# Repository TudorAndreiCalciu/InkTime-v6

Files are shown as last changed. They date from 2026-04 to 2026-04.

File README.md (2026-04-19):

# InkTime v6 - Smartwatch cu Display E-Paper (nRF52840)

InkTime v6 este un proiect hardware de tip wearable, conceput pentru eficiență energetică extremă și afișaj permanent. Dispozitivul utilizează un ecran E-Paper de 1.54 inch și este bazat pe microcontrolerul nRF52840, oferind conectivitate Bluetooth Low Energy (BLE) într-un format compact.

---

## 1. Diagrama Bloc a Sistemului

Această diagramă ilustrează arhitectura hardware și fluxul de alimentare și date între module:

```mermaid
graph TD
    subgraph "Power Management"
        BATT((Baterie LiPo 3.7V)) --> CHG[Charger TP4056]
        CHG --> LDO[Regulator LDO 3.3V AP2112K]
    end

    subgraph "Processing Core"
        MCU[Holyiot nRF52840<br/>ARM Cortex-M4F]
    end

    subgraph "Peripherals"
        EPD[Display E-Paper 1.54'']
        SENS[Senzori I2C + Pull-ups]
        BTNS[3x User Buttons]
        DEBUG[Interfață Debug SWD]
    end

    %% Conexiuni Alimentare
    LDO -->|3.3V VCC| MCU
    LDO -->|3.3V VCC| EPD
    LDO -->|3.3V VCC| SENS

    %% Conexiuni Date
    MCU <-->|SPI Bus| EPD
    MCU <-->|I2C SDA/SCL| SENS
    BTNS ---|GPIO / Interrupt| MCU
    DEBUG <-->|SWDIO / SWCLK| MCU
```

---

## 2. Descrierea Hardware și Funcționalitate

Dispozitivul a fost proiectat respectând principiile de consum ultra-scăzut (Ultra-Low Power):

* **Microcontroler (MCU):** Modulul **Holyiot nRF52840**. Ales pentru consumul minim în modul Deep Sleep (~3µA) și pentru suportul nativ de conectivitate BLE și USB. Acesta gestionează întreaga logică a ceasului.
* **Display E-Paper:** Un ecran de 1.54 inch conectat prin magistrala **SPI**. Tehnologia bistabilă permite afișarea permanentă a informațiilor fără consum de energie (0mA în stare statică).
* **Interfața I2C:** Configurație cu rezistențe de pull-up de 4.7kΩ pentru a asigura stabilitatea semnalului către senzori (accelerometru/RTC).
* **Management Alimentare:** Încărcarea bateriei LiPo se face prin portul USB utilizând controller-ul **TP4056**. Tensiunea este stabilizată la 3.3V prin regulatorul LDO **AP2112K-3.3**.

---

## 3. Maparea Pinilor (Pinout nRF52840)

Alocarea pinilor a fost realizată strategic pentru a facilita rutarea semnalelor pe PCB:

| Pin nRF52 | Conectat la | Interfață | Rol / Justificare |
| :--- | :--- | :--- | :--- |
| **P1.00** | `EPD_MOSI` | SPI | Date transmise către display. |
| **P0.22** | `EPD_SCK` | SPI | Semnalul de tact (Clock) pentru SPI. |
| **P0.20** | `EPD_CS` | SPI (CS) | Chip Select - Activează display-ul. |
| **P0.17** | `EPD_DC` | GPIO | Data/Command - Comută între date și comenzi. |
| **P0.15** | `EPD_RES` | GPIO | Reset Hardware - Inițializează driverul EPD. |
| **P0.13** | `EPD_BUSY` | GPIO (In) | Busy Signal - Detectează finalul refresh-ului. |
| **P0.26** | `I2C_SDA` | I2C | Date pentru magistrala I2C. |
| **P0.24** | `I2C_SCL` | I2C | Clock pentru magistrala I2C. |
| **P0.02** | `BTN1` | GPIO (IRQ) | Buton 1 - Configurat pentru Wake-up. |
| **P0.29** | `BTN2` | GPIO | Buton 2 - Input utilizator (Sus/Select). |
| **P0.31** | `BTN3` | GPIO | Buton 3 - Input utilizator (Jos/Back). |
| **P0.11** | `SWCLK` | Debug | Clock pentru programare (Hardware dedicated). |
| **P0.12** | `SWDIO` | Debug | Date pentru programare (Hardware dedicated). |

---

## 4. Bill of Materials (BOM)

Componentele utilizate pe placă cu link-uri către JLCPCB și documentație:

| Componentă | Pachet | Rol | Link JLCPCB | Datasheet |
| :--- | :--- | :--- | :--- | :--- |
| **nRF52840 Holyiot** | SMD Module | MCU + BLE | [C517331](https://jlcpcb.com/partdetail/C517331) | [Link PDF](https://www.mouser.com/datasheet/3/926/1/nrf52840_soc_v3.0.pdf) |
| **AP2112K-3.3** | SOT-23-5 | LDO 3.3V | [C51118](https://jlcpcb.com/partdetail/C51118) | [Link PDF](https://www.diodes.com/assets/Datasheets/AP2112.pdf) |
| **TP4056** | SOP-8 | Charger | [C16581](https://jlcpcb.com/partdetail/C16581) | [Link PDF](https://dlnmh9ip6v2uc.cloudfront.net/datasheets/Prototyping/TP4056.pdf) |
| **Butoane Tactile** | 3x4mm SMD | Input | [C318884](https://jlcpcb.com/partdetail/C318884) | [Link PDF](https://datasheet.lcsc.com/lcsc/1811061726_XKB-Connection-TS-1187A-B-A-B_C318884.pdf) |
| **Conector FPC 24P** | 0.5mm Pitch | EPD Port | [C46954](https://jlcpcb.com/partdetail/C46954) | [Link PDF](https://datasheet.lcsc.com/lcsc/1810010313_XKB-Enterprise-F31L-1A7H1-24050-T241_C46954.pdf) |

---

## 5. Analiza Consumului Energetic

Sistemul este proiectat să funcționeze cu o baterie LiPo de **250 mAh**.

* **Consum Deep Sleep:** ~5 µA (MCU + LDO quiescent current).
* **Consum Refresh E-Paper:** ~8 mA (timp de 2 secunde).
* **Consum Mediu:** ~0.27 mA (calculat pentru un refresh pe minut).
* **Autonomie Estimată:** Aproximativ **38 de zile** de funcționare continuă.

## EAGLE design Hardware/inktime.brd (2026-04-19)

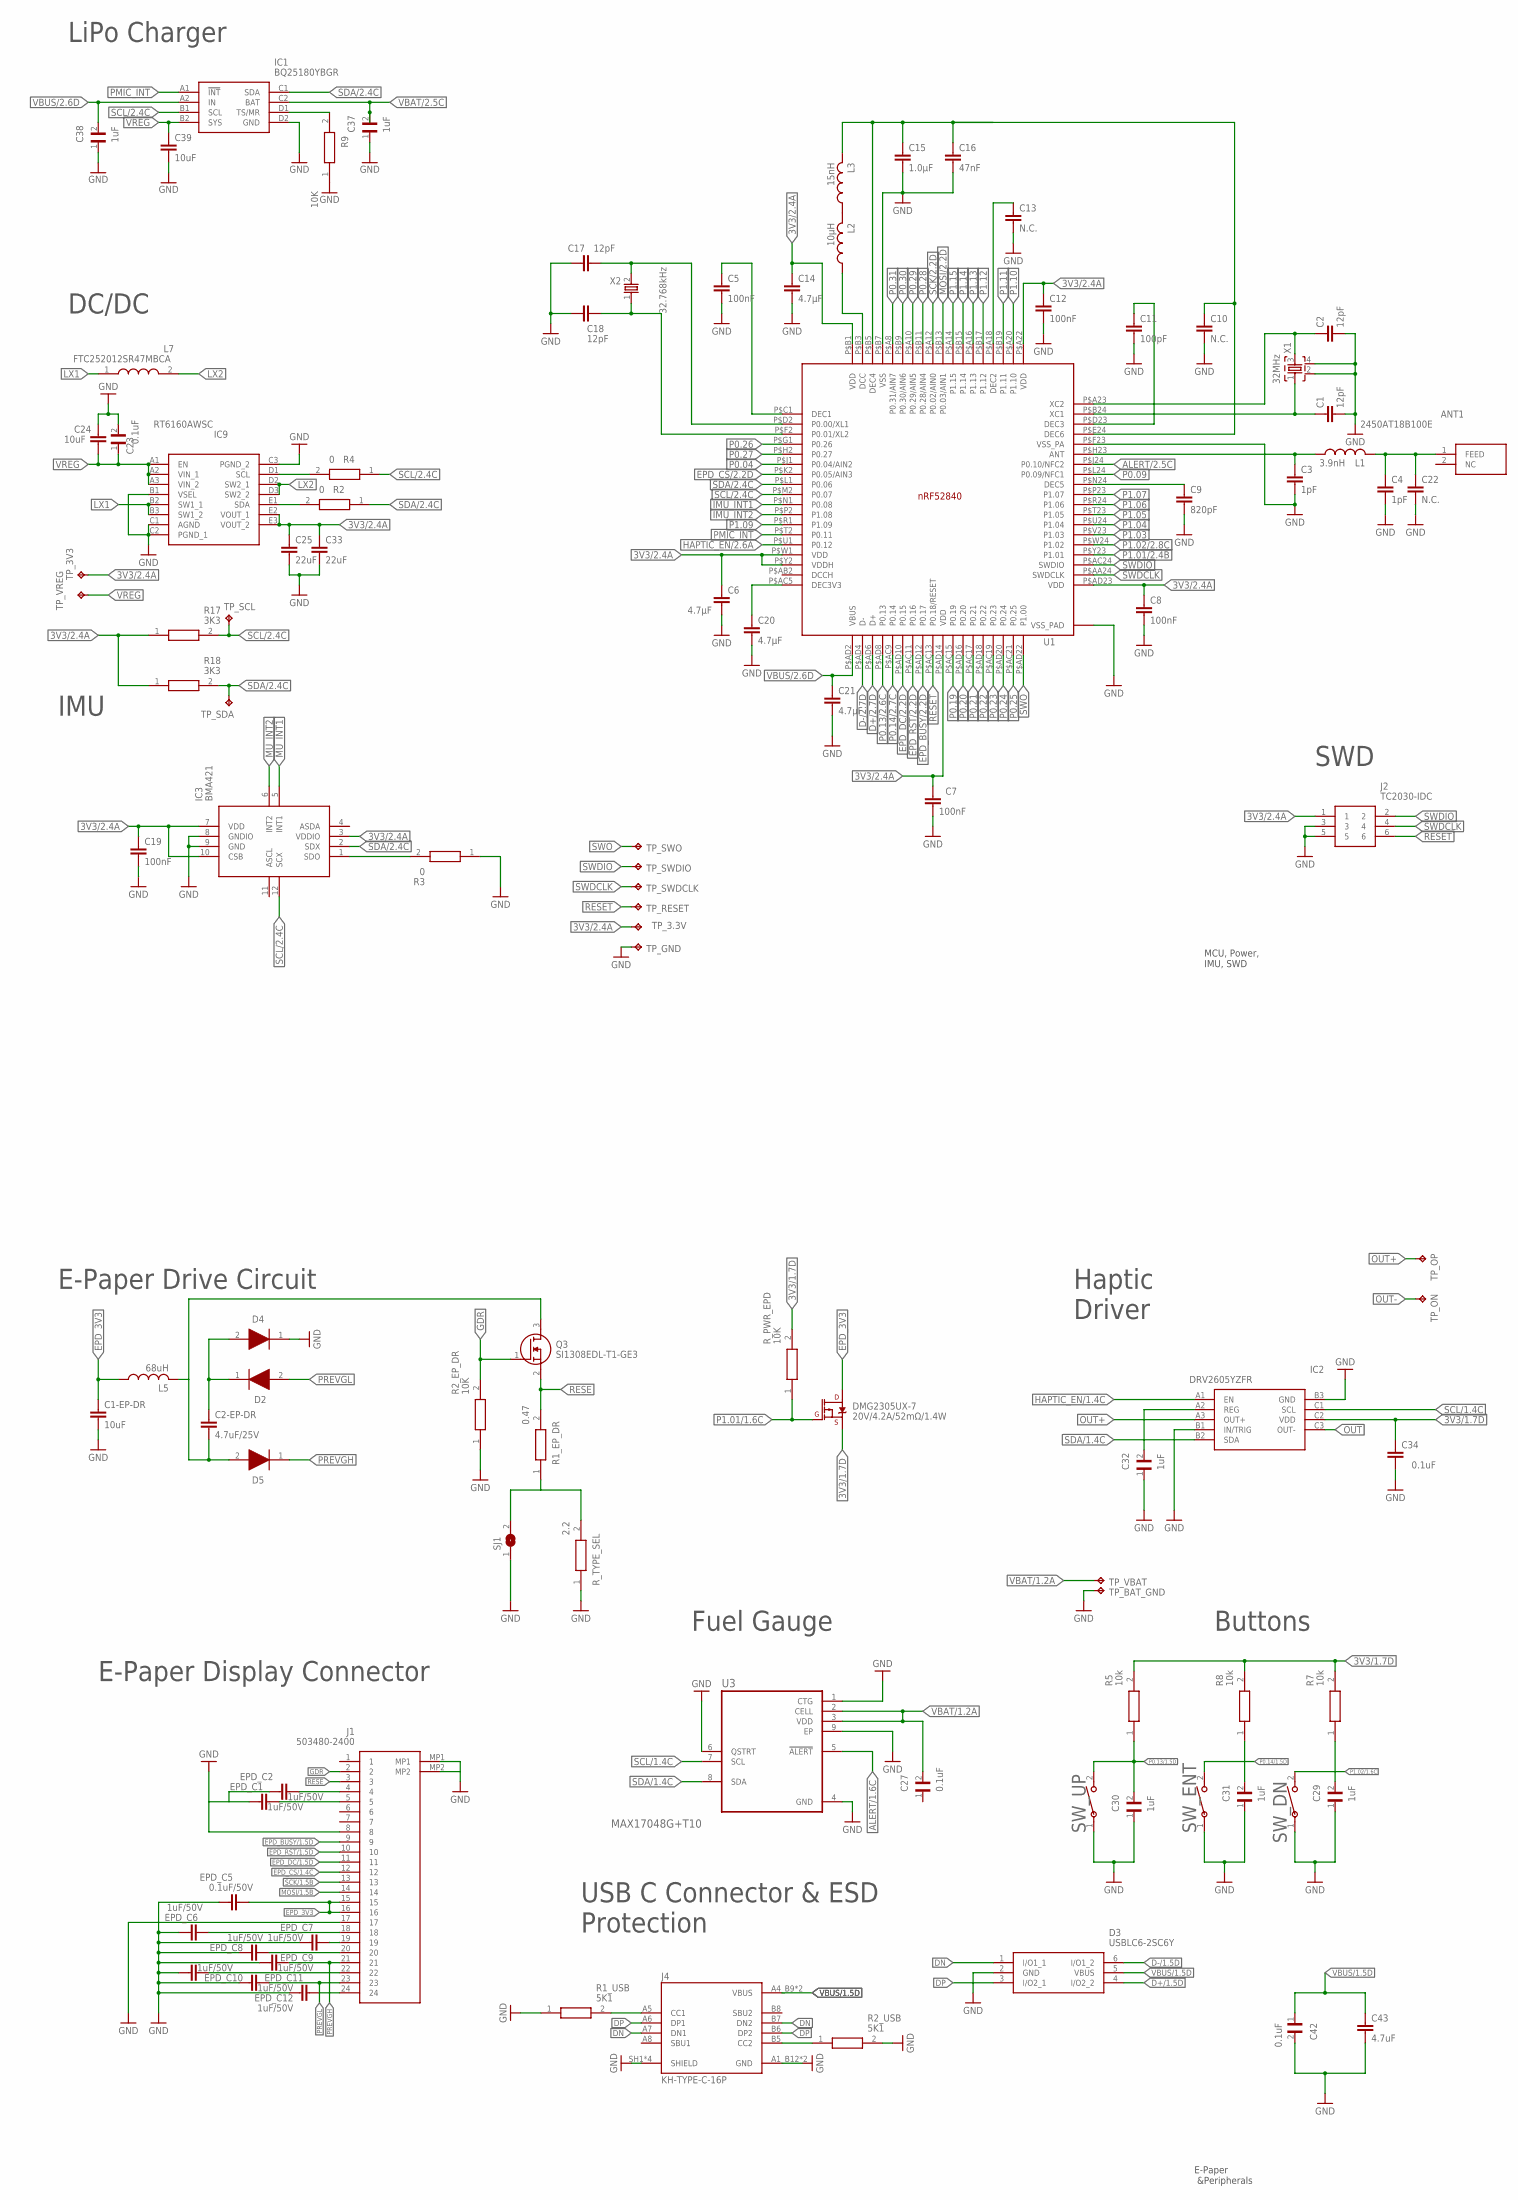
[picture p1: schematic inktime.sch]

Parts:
ANT1: 2450AT18B100E; 2450AT18B100E_ANTC3216X140N
C1, C2, C17, C18: 12pF; NORDIC_NRF_3_RESC0201_L
C1-EP-DR, C39: 10uF; NORDIC_NRF_3_RESC0201_L
C2-EP-DR: 4.7uF/25V; NORDIC_NRF_3_RESC0201_L
C3, C4: 1pF; NORDIC_NRF_3_RESC0201_L
C5, C7, C8, C12, C19: 100nF; NORDIC_NRF_3_RESC0201_L
C6: 4.7µF; NORDIC_NRF_3_RESC0201_L
C9: 820pF; NORDIC_NRF_3_RESC0201_L
C10, C13, C22: N.C.; NORDIC_NRF_3_RESC0201_L
C11: 100pF; NORDIC_NRF_3_RESC0201_L
C14, C20, C21: 4.7µF; ESP32_C6_LIBRARY_1_ESP32_WROVER_EAGLE-LTSPICE_C0402
C15: 1.0µF; NORDIC_NRF_3_RESC0201_L
C16: 47nF; NORDIC_NRF_3_RESC0201_L
C23, C27, C42: 0.1uF; GRM011R60J152KE01L_2_CAPC0201X13N
C24: 10uF; ESP32_C6_LIBRARY_1_ESP32_WROVER_EAGLE-LTSPICE_C0402
C25, C33: 22uF; ESP32_C6_LIBRARY_1_ESP32_WROVER_EAGLE-LTSPICE_C0402
C29, C30, C31, C32, C37, C38: 1uF; GRM011R60J152KE01L_2_CAPC0201X13N
C34: 0.1uF; NORDIC_NRF_3_RESC0201_L
C43: 4.7uF; ESP32_C6_LIBRARY_1_ESP32_WROVER_EAGLE-LTSPICE_C0402
D2, D4, D5: ESP32_C6_LIBRARY_5_MBR0530; ESP32_C6_LIBRARY_5_SOD3716X135N
D3: USBLC6-2SC6Y; ESP32_C6_LIBRARY_3_SOT95P280X145-6N
DMG2305UX-7: 20V/4.2A/52mΩ/1.4W; ESP32_C6_LIBRARY_4_ESP32_C6_LIBRARY_4_ESP32_C6_LIBRARY_4_ES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
EPD_C1, EPD_C2, EPD_C6, EPD_C7, EPD_C8, EPD_C9, EPD_C10, EPD_C11, EPD_C12: 1uF/50V; ESP32_C6_LIBRARY_1_ESP32_WROVER_EAGLE-LTSPICE_C0402
EPD_C5: 0.1uF/50V; ESP32_C6_LIBRARY_1_ESP32_WROVER_EAGLE-LTSPICE_C0402
IC1: BQ25180YBGR; BQ25180YBGR_BGA8C40P2X4_100X155X50
IC2: DRV2605YZFR; DRV2605YZFR_BGA9C50P3X3_144X144X62
IC3: BMA421; BMA423_BMA423
IC9: RT6160AWSC; RT6160AWSC_BGA15C40P3X5_140X230X60
J1: 503480-2400; 503480-2400_5034802400
J2: TC2030-IDC; TC2030-IDC_TC2030IDC
J4: KH-TYPE-C-16P; KH-TYPE-C-16P_KINGHELM_KH-TYPE-C-16P
L1: 3.9nH; NORDIC_NRF_2_RESC0402_L
L2: 10µH; NORDIC_NRF_2_RESC0402_L
L3: 15nH; NORDIC_NRF_2_RESC0402_L
L5: 68uH; NORDIC_NRF_2_RESC0402_L
L7: FTC252012SR47MBCA; MLP2016SR47MT0S1_INDC2016X100N
Q3: SI1308EDL-T1-GE3; ESP32_C6_LIBRARY_6_SOT65P210X110-3N
R1_EP_DR: 0.47; ERA-1AEB3401C_0201
R1_USB: 5K1; CPF0201D7K68C1_0201
R2, R4: 0; CPF0201D7K68C1_0201
R2_EP_DR, R9: 10K; ERA-1AEB3401C_0201
R2_USB: 5K1; ERA-1AEB3401C_0201
R3: 0; ERA-1AEB3401C_0201
R5, R7, R8: 10k; CPF0201D7K68C1_0201
R17, R18: 3K3; CPF0201D7K68C1_0201
R_PWR_EPD: 10K; CPF0201D7K68C1_0201
R_TYPE_SEL: 2.2; ERA-1AEB3401C_0201
SJ1: ESP32_C6_LIBRARY_7_JUMPER_SJ
SW_DN: 2025-10-22_07-23-44_LIBRARY_EVP-AKE31ASW_EVP-AKE3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; 2025-10-22_07-23-44_LIBRARY_SW_EVP-AKE31A_PAN
SW_ENT: 2025-10-22_07-23-44_LIBRARY_EVP-AKE31ASW_EVP-AKE3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; 2025-10-22_07-23-44_LIBRARY_SW_EVP-AKE31A_PAN
SW_UP: 2025-10-22_07-23-44_LIBRARY_EVP-AKE31ASW_EVP-AKE3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; 2025-10-22_07-23-44_LIBRARY_SW_EVP-AKE31A_PAN
TP_3.3V, TP_3V3: HECTOR_WATCH_1_TPTP20R; HECTOR_WATCH_1_TP20R
TP_BAT_GND: HECTOR_WATCH_1_TPTP20R; HECTOR_WATCH_1_TP20R
TP_GND: HECTOR_WATCH_1_TPTP20R; HECTOR_WATCH_1_TP20R
TP_ON: HECTOR_WATCH_1_TPTP20R; HECTOR_WATCH_1_TP20R
TP_OP: HECTOR_WATCH_1_TPTP20R; HECTOR_WATCH_1_TP20R
TP_RESET: HECTOR_WATCH_1_TPTP20R; HECTOR_WATCH_1_TP20R
TP_SCL: HECTOR_WATCH_1_TPTP20R; HECTOR_WATCH_1_TP20R
TP_SDA: HECTOR_WATCH_1_TPTP20R; HECTOR_WATCH_1_TP20R
TP_SWDCLK: HECTOR_WATCH_1_TPTP20R; HECTOR_WATCH_1_TP20R
TP_SWDIO: HECTOR_WATCH_1_TPTP20R; HECTOR_WATCH_1_TP20R
TP_SWO: HECTOR_WATCH_1_TPTP20R; HECTOR_WATCH_1_TP20R
TP_VBAT: HECTOR_WATCH_1_TPTP20R; HECTOR_WATCH_1_TP20R
TP_VREG: HECTOR_WATCH_1_TPTP20R; HECTOR_WATCH_1_TP20R
U1: NRF52840_QF; NORDIC_NRF_4_AQFN50P700X700X85_HS-74N
U3: MAX17048G+T10; ESP32_C6_LIBRARY_SON50P200X200X80-9N
X1: 32MHz; NORDIC_NRF_BT-XTAL_2016_N
X2: 32.768kHz; NORDIC_NRF_1_XTAL_3215_N

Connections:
3V3/1.7D: C34.1, DMG2305UX-7.2 (S), IC2.C2 (VDD), R5.2, R7.2, R8.2, R_PWR_EPD.2
3V3/2.4A: C6.1, C7.1, C8.1, C12.1, C14.1, C19.1, C25.1, C33.1, IC3.3 (VDDIO), IC3.7 (VDD), IC3.10 (CSB), IC9.E2 (VOUT_1), IC9.E3 (VOUT_2), J2.1, R17.1, R18.1, TP_3.3V.TP, TP_3V3.TP, U1.P$A22 (VDD), U1.P$AD14 (VDD), U1.P$AD23 (VDD), U1.P$B1 (VDD), U1.P$W1 (VDD), U1.P$Y2 (VDDH)
ALERT/1.6C: U3.5 (!ALERT)
ALERT/2.5C: U1.P$J24 (P0.10/NFC2)
D+/1.5D: D3.4 (I/O2_2)
D+/2.7D: U1.P$AD6 (D+)
D-/1.5D: D3.6 (I/O1_2)
D-/2.7D: U1.P$AD4 (D-)
DN: D3.1 (I/O1_1), J4.A7 (DN1), J4.B7 (DN2)
DP: D3.3 (I/O2_1), J4.A6 (DP1), J4.B6 (DP2)
EPD_3V3: C1-EP-DR.1, DMG2305UX-7.3 (D), EPD_C5.2, J1.15, J1.16, L5.1
EPD_BUSY/1.5D: J1.9
EPD_BUSY/2.2D: U1.P$AD12 (P0.17)
EPD_CS/1.4C: J1.12
EPD_CS/2.2D: U1.P$K2 (P0.05/AIN3)
EPD_DC/1.5D: J1.11
EPD_DC/2.2D: U1.P$AD10 (P0.15)
EPD_RST/1.5D: J1.10
EPD_RST/2.2D: U1.P$AC11 (P0.16)
GDR: J1.2, Q3.1 (G), R2_EP_DR.2
GND: C1.2, C1-EP-DR.2, C2.2, C3.2, C4.2, C5.2, C6.2, C7.2, C8.2, C9.2, C10.2, C11.2, C12.2, C13.2, C14.2, C15.2, C16.2, C17.1, C18.2, C19.2, C20.2, C21.2, C22.2, C23.2, C24.1, C25.2, C29.1, C30.1, C31.1, C32.1, C33.2, C34.2, C37.1, C38.1, C39.2, C42.2, C43.2, D3.2 (GND), D4.1 (K), EPD_C5.1, EPD_C6.1, EPD_C7.1, EPD_C8.1, EPD_C9.1, EPD_C10.1, EPD_C11.1, EPD_C12.1, IC1.D2 (GND), IC2.B1 (IN/TRIG), IC2.B3 (GND), IC3.8 (GNDIO), IC3.9 (GND), IC9.B1 (VSEL), IC9.C1 (AGND), IC9.C2 (PGND_1), IC9.C3 (PGND_2), J1.8, J1.17, J1.MP1, J2.3, J2.5, J4.A1_B12 (GND), J4.A12_B1 (GND), J4.SH1 (SHIELD), J4.SH2 (SHIELD), J4.SH3 (SHIELD), J4.SH4 (SHIELD), R1_USB.1, R2_EP_DR.1, R2_USB.2, R3.1, R9.1, R_TYPE_SEL.1, SJ1.1, SW_DN.1, SW_ENT.1, SW_UP.1, TP_BAT_GND.TP, TP_GND.TP, U1.P$74 (VSS_PAD), U1.P$75 (VSS_PAD), U1.P$76 (VSS_PAD), U1.P$77 (VSS_PAD), U1.P$78 (VSS_PAD), U1.P$79 (VSS_PAD), U1.P$80 (VSS_PAD), U1.P$81 (VSS_PAD), U1.P$82 (VSS_PAD), U1.P$83 (VSS_PAD), U1.P$84 (VSS_PAD), U1.P$85 (VSS_PAD), U1.P$86 (VSS_PAD), U1.P$87 (VSS_PAD), U1.P$88 (VSS_PAD), U1.P$89 (VSS_PAD), U1.P$90 (VSS_PAD), U1.P$B7 (VSS), U1.P$F23 (VSS_PA), U3.1 (CTG), U3.4 (GND), U3.6 (QSTRT), U3.9 (EP), X1.2, X1.4
HAPTIC_EN/1.4C: IC2.A1 (EN)
HAPTIC_EN/2.6A: U1.P$U1 (P0.12)
IMU_INT1: U1.P$N1 (P0.08)
IMU_INT2: U1.P$P2 (P1.08)
JJ: C10.1, C15.1, C16.1, L3.2, U1.P$B5 (DEC4), U1.P$E24 (DEC6)
LX1: IC9.B2 (SW1_1), IC9.B3 (SW1_2), L7.1
LX2: IC9.D2 (SW2_1), IC9.D3 (SW2_2), L7.2
MOSI/1.5B: J1.14
MOSI/2.2D: U1.P$B13 (P0.03/AIN1)
MU_INT1: IC3.5 (INT1)
MU_INT2: IC3.6 (INT2)
unnamed: IC1.D1 (TS/MR), R9.2
unnamed: IC9.D1 (SCL), R4.2
unnamed: IC9.E1 (SDA), R2.2
unnamed: IC3.1 (SDO), R3.2
unnamed: C20.1, U1.P$AC5 (DEC3V3)
unnamed: C18.1, U1.P$F2 (P0.01/XL2), X2.1
unnamed: C17.2, U1.P$D2 (P0.00/XL1), X2.2
unnamed: C5.1, U1.P$C1 (DEC1)
unnamed: C9.1, U1.P$N24 (DEC5)
unnamed: L2.1, U1.P$B3 (DCC)
unnamed: L2.2, L3.1
unnamed: C3.1, L1.1, U1.P$H23 (ANT)
unnamed: ANT1.1 (FEED), C4.1, C22.1, L1.2
unnamed: C11.1, U1.P$D23 (DEC3)
unnamed: C2.1, U1.P$A23 (XC2), X1.3
unnamed: C1.1, U1.P$B24 (XC1), X1.1
unnamed: C2-EP-DR.2, D5.2 (A), L5.2, Q3.3 (D)
unnamed: C2-EP-DR.1, D2.1 (K), D4.2 (A)
unnamed: R1_EP_DR.1, R_TYPE_SEL.2, SJ1.2
unnamed: C13.1, U1.P$A18 (DEC2)
unnamed: C32.2, IC2.A2 (REG)
unnamed: EPD_C2.2, J1.4
unnamed: EPD_C1.2, J1.5
unnamed: EPD_C6.2, J1.18
unnamed: EPD_C7.2, J1.19
unnamed: EPD_C8.2, J1.20
unnamed: J4.A5 (CC1), R1_USB.2
unnamed: EPD_C10.2, J1.22
unnamed: C31.2, R8.1
unnamed: EPD_C12.2, J1.24
unnamed: J4.B5 (CC2), R2_USB.1
unnamed: C29.2, R7.1
OUT: IC2.C3 (OUT-)
OUT+: IC2.A3 (OUT+), TP_OP.TP
OUT-: TP_ON.TP
P0.04: U1.P$J1 (P0.04/AIN2)
P0.09: U1.P$L24 (P0.09/NFC1)
P0.13/1.5D: C30.2, R5.1, SW_UP.2
P0.13/2.6C: U1.P$AD8 (P0.13)
P0.14/1.5D: SW_ENT.2
P0.14/2.7C: U1.P$AC9 (P0.14)
P0.19: U1.P$AC15 (P0.19)
P0.20: U1.P$AD16 (P0.20)
P0.21: U1.P$AC17 (P0.21)
P0.22: U1.P$AD18 (P0.22)
P0.23: U1.P$AC19 (P0.23)
P0.24: U1.P$AD20 (P0.24)
P0.25: U1.P$AC21 (P0.25)
P0.26: U1.P$G1 (P0.26)
P0.27: U1.P$H2 (P0.27)
P0.28: U1.P$B11 (P0.28/AIN4)
P0.29: U1.P$A10 (P0.29/AIN5)
P0.30: U1.P$B9 (P0.30/AIN6)
P0.31: U1.P$A8 (P0.31/AIN7)
P1.01/1.6C: DMG2305UX-7.1 (G), R_PWR_EPD.1
P1.01/2.4B: U1.P$Y23 (P1.01)
P1.02/1.6C: SW_DN.2
P1.02/2.8C: U1.P$W24 (P1.02)
P1.03: U1.P$V23 (P1.03)
P1.04: U1.P$U24 (P1.04)
P1.05: U1.P$T23 (P1.05)
P1.06: U1.P$R24 (P1.06)
P1.07: U1.P$P23 (P1.07)
P1.09: U1.P$R1 (P1.09)
P1.10: U1.P$A20 (P1.10)
P1.11: U1.P$B19 (P1.11)
P1.12: U1.P$B17 (P1.12)
P1.13: U1.P$A16 (P1.13)
P1.14: U1.P$B15 (P1.14)
P1.15: U1.P$A14 (P1.15)
PMIC_INT: IC1.A1 (!INT), U1.P$T2 (P0.11)
PREVGH: D5.1 (K), EPD_C9.2, J1.21
PREVGL: D2.2 (A), EPD_C11.2, J1.23
RESE: J1.3, Q3.2 (S), R1_EP_DR.2
RESET: J2.6, TP_RESET.TP, U1.P$AC13 (P0.18/RESET)
SCK/1.5B: J1.13
SCK/2.2D: U1.P$A12 (P0.02/AIN0)
SCL/1.4C: IC2.C1 (SCL), U3.7 (SCL)
SCL/2.4C: IC1.B1 (SCL), IC3.12 (SCX), R4.1, R17.2, TP_SCL.TP, U1.P$M2 (P0.07)
SDA/1.4C: IC2.B2 (SDA), U3.8 (SDA)
SDA/2.4C: IC1.C1 (SDA), IC3.2 (SDX), R2.1, R18.2, TP_SDA.TP, U1.P$L1 (P0.06)
SWDCLK: J2.4, TP_SWDCLK.TP, U1.P$AA24 (SWDCLK)
SWDIO: J2.2, TP_SWDIO.TP, U1.P$AC24 (SWDIO)
SWO: TP_SWO.TP, U1.P$AD22 (P1.00)
VBAT/1.2A: C27.2, TP_VBAT.TP, U3.2 (CELL), U3.3 (VDD)
VBAT/2.5C: C37.2, IC1.C2 (BAT)
VBUS/1.5D: C42.1, C43.1, D3.5 (VBUS), J4.A4_B9 (VBUS), J4.A9_B4 (VBUS)
VBUS/2.6D: C21.1, C38.2, IC1.A2 (IN), U1.P$AD2 (VBUS)
VREG: C23.1, C24.2, C39.1, IC1.B2 (SYS), IC9.A1 (EN), IC9.A2 (VIN_1), IC9.A3 (VIN_2), TP_VREG.TP

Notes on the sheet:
LiPo Charger
DC/DC
IMU
SWD
MCU, Power, IMU, SWD
E-Paper Drive Circuit
Haptic Driver
E-Paper Display Connector
Fuel Gauge
Buttons
E-Paper &Peripherals
USB C Connector & ESD Protection

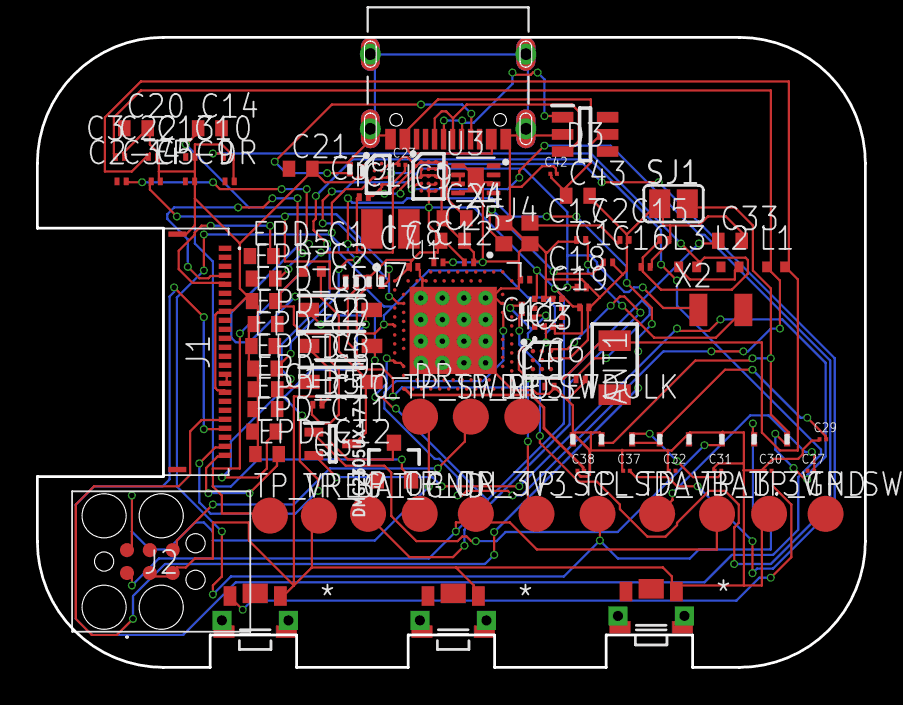
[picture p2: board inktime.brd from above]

Board: 2 copper layers, 46.0 x 35.0 mm, 105 parts (0 on the bottom side), 62 nets.

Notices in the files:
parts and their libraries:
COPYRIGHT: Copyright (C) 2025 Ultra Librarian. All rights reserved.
